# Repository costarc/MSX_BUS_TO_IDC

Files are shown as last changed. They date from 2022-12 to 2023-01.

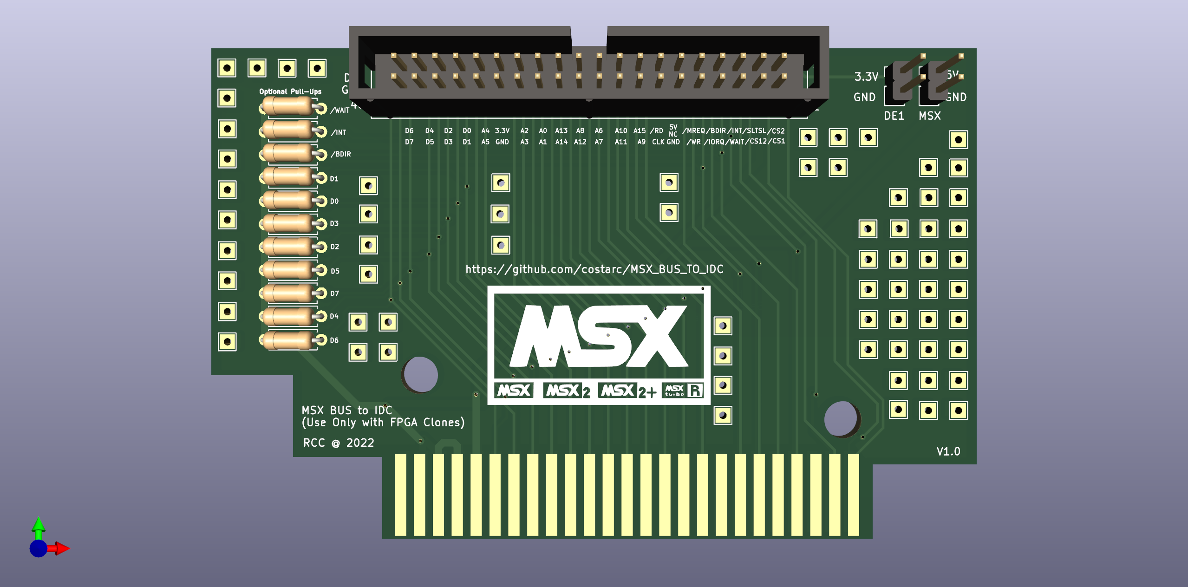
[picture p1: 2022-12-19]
MSX_BUS_TO_IDC.png

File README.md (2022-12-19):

# MSX_BUS_TO_IDC

V1.0

This MSX interface exposes the MSX BUS via an IDC connector.
The IDC pinout layout matches the Altera DE1 Development board.

There is no voltage level conversion, therefore this interface must be used only with MSX FPGA clones
because they already operate at 3.3v level.

Do ont use this interface to connect a real MSX (which operates with a 5V bus) to the Altra DE1.

The pull-ups resistors are optional. They may be installed if you determine that your project requires pull-ups in those lines.

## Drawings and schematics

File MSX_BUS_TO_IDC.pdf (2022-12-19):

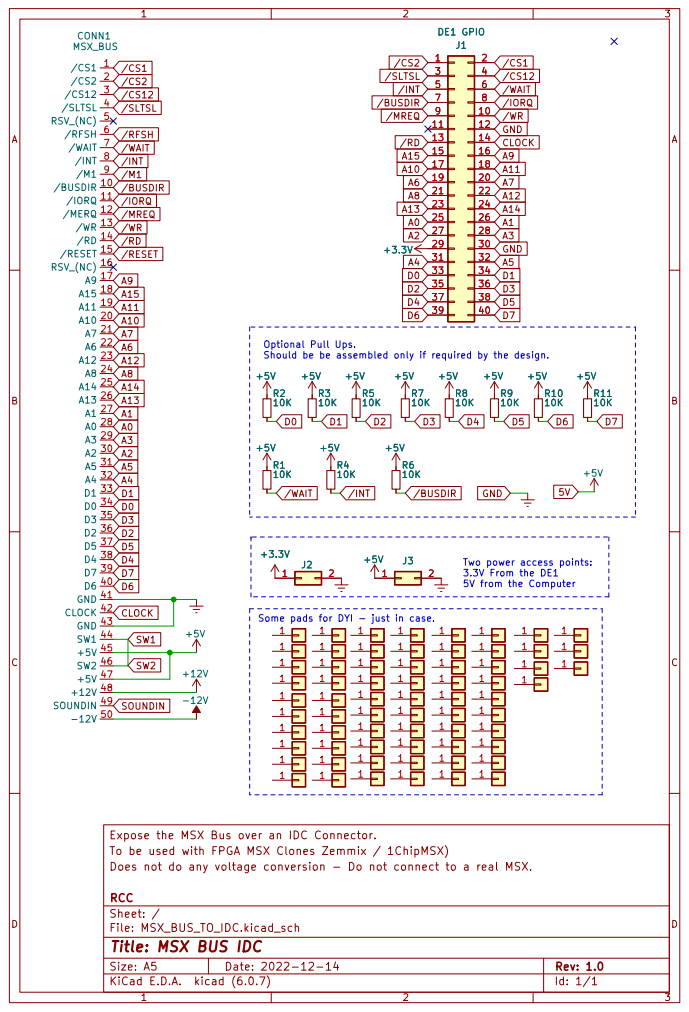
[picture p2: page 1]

Optional Pull Ups.
Should be be assembled only if required by the design.

Two power access points: 3.3V From the DE1

To be used with FPGA MSX Clones Zemmix / 1ChipMSX)
Does not do any voltage conversion - Do not connect to a real MSX.

Id: 1/1 Title: MSX BUS IDC

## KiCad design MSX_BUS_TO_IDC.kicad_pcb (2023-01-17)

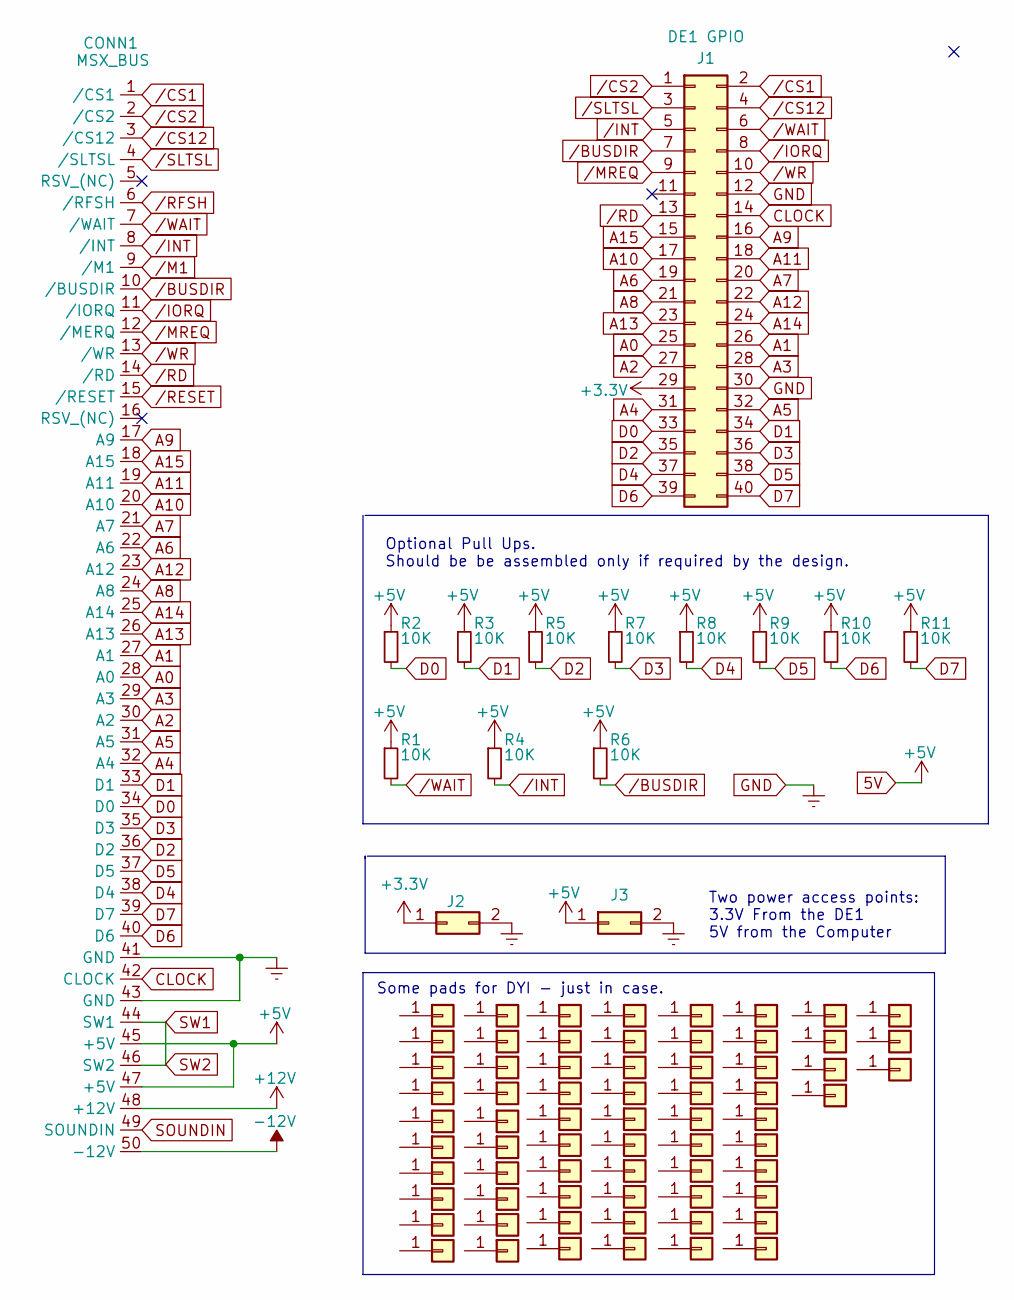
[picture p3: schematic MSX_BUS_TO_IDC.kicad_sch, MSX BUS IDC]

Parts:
CONN1: MSX_BUS; MSX_CART
J1: DE1 GPIO; IDC-Header_2x20_P2.54mm_Vertical
J2, J3: Conn_02x01; PinHeader_1x02_P2.54mm_Vertical
J4, J5, J6, J7, J8, J9, J10, J11, J12, J13, J14, J15, J16, J17, J18, J19, J20, J21, J22, J23, J24, J25, J26, J27, J28, J29, J30, J31, J32, J33, J34, J35, J36, J37, J38, J39, J40, J41, J42, J43, J44, J45, J46, J47, J48, J49, J50, J51, J52, J53, J54, J55, J56, J57, J58, J59, J60, J61, J62, J63, J64, J65, J66, J67, J68, J69, J70: Conn_01x01; TestPoint_THTPad_2.0x2.0mm_Drill1.0mm
R1, R2, R3, R4, R5, R6, R7, R8, R9, R10, R11: 10K; R_Axial_DIN0207_L6.3mm_D2.5mm_P7.62mm_Horizontal

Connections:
5V: CONN1.45 (+5V), CONN1.47 (+5V), J3.1, R1.1, R2.1, R3.1, R4.1, R5.1, R6.1, R7.1, R8.1, R9.1, R10.1, R11.1
+3.3V: J1.29, J2.1
+12V: CONN1.48 (+12V)
-12V: CONN1.50 (-12V)
A0: CONN1.28 (A0), J1.25
A1: CONN1.27 (A1), J1.26
A2: CONN1.30 (A2), J1.27
A3: CONN1.29 (A3), J1.28
A4: CONN1.32 (A4), J1.31
A5: CONN1.31 (A5), J1.32
A6: CONN1.22 (A6), J1.19
A7: CONN1.21 (A7), J1.20
A8: CONN1.24 (A8), J1.21
A9: CONN1.17 (A9), J1.16
A10: CONN1.20 (A10), J1.17
A11: CONN1.19 (A11), J1.18
A12: CONN1.23 (A12), J1.22
A13: CONN1.26 (A13), J1.23
A14: CONN1.25 (A14), J1.24
A15: CONN1.18 (A15), J1.15
CLOCK: CONN1.42 (CLOCK), J1.14
D0: CONN1.34 (D0), J1.33, R2.2
D1: CONN1.33 (D1), J1.34, R3.2
D2: CONN1.36 (D2), J1.35, R5.2
D3: CONN1.35 (D3), J1.36, R7.2
D4: CONN1.38 (D4), J1.37, R8.2
D5: CONN1.37 (D5), J1.38, R9.2
D6: CONN1.40 (D6), J1.39, R10.2
D7: CONN1.39 (D7), J1.40, R11.2
GND: CONN1.41 (GND), CONN1.43 (GND), J1.12, J1.30, J2.2, J3.2
SOUNDIN: CONN1.49 (SOUNDIN)
SW1: CONN1.44 (SW1), CONN1.46 (SW2)
/BUSDIR: CONN1.10 (/BUSDIR), J1.7, R6.2
/CS1: CONN1.1 (/CS1), J1.2
/CS2: CONN1.2 (/CS2), J1.1
/CS12: CONN1.3 (/CS12), J1.4
/INT: CONN1.8 (/INT), J1.5, R4.2
/IORQ: CONN1.11 (/IORQ), J1.8
/M1: CONN1.9 (/M1)
/MREQ: CONN1.12 (/MERQ), J1.9
/RD: CONN1.14 (/RD), J1.13
/RESET: CONN1.15 (/RESET)
/RFSH: CONN1.6 (/RFSH)
/SLTSL: CONN1.4 (/SLTSL), J1.3
/WAIT: CONN1.7 (/WAIT), J1.6, R1.2
/WR: CONN1.13 (/WR), J1.10

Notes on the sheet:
Two power access points: 3.3V From the DE1 5V from the Computer
Some pads for DYI - just in case.
Optional Pull Ups. Should be be assembled only if required by the design.

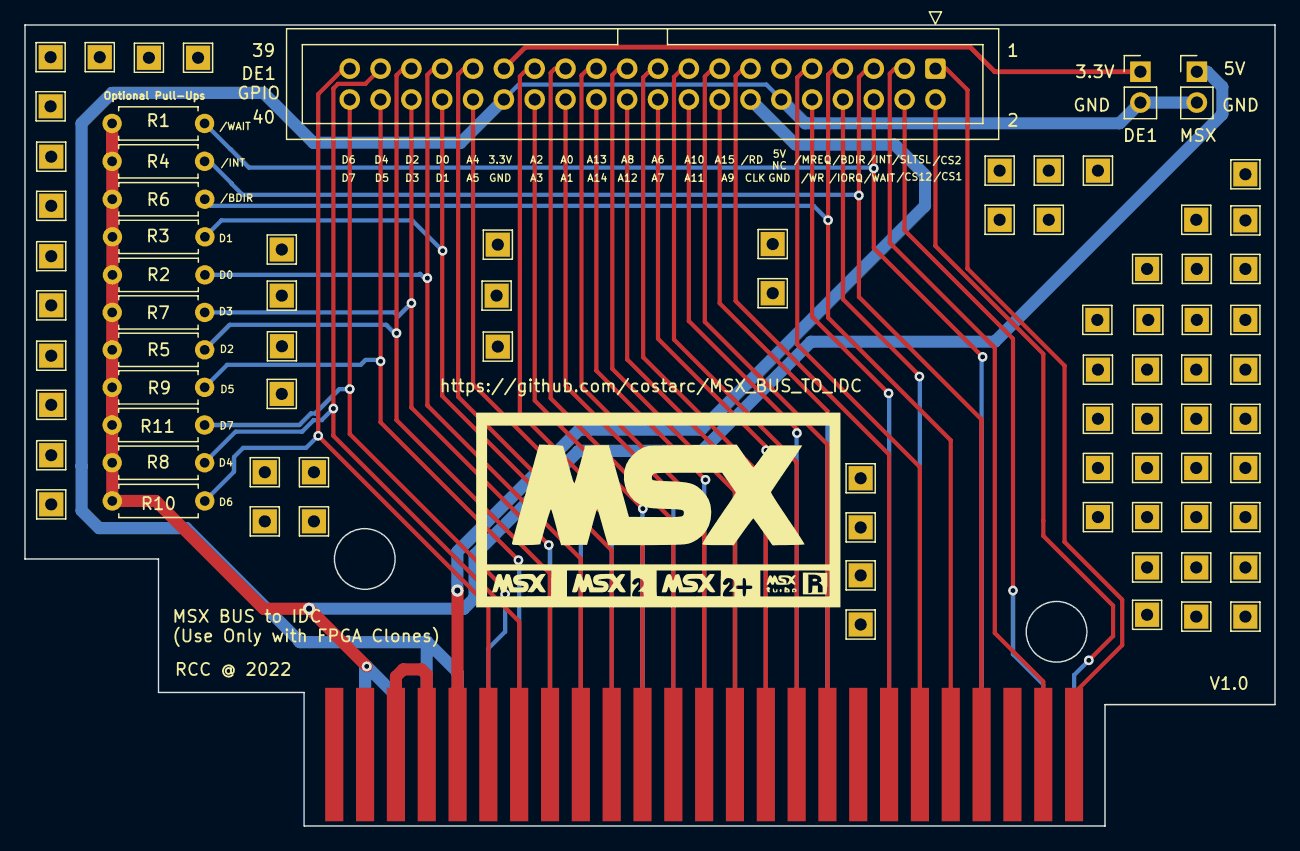
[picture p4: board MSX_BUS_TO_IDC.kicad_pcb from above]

Board: 2 copper layers, 103.0 x 66.0 mm, 82 parts (0 on the bottom side), 40 nets.

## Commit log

2022-12-19 Fabrication files added
    [MSX_BUS_TO_IDC.kicad_pcb]
2022-12-19 Adjusted footprints for resistors
    [MSX_BUS_TO_IDC.kicad_pcb, MSX_BUS_TO_IDC.kicad_sch]
2023-01-17 Added Gerber files
